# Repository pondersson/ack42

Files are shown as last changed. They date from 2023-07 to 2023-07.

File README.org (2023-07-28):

* ACK42

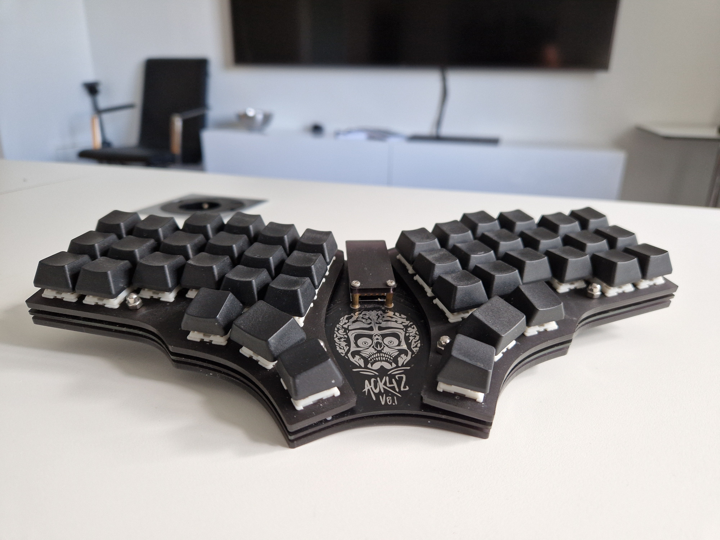
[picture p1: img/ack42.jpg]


ACK42 is a DIY sandwich-style keyboard with 42 keys inspired by [[https://zealot.hu/absolem/][Absolem]], [[https://github.com/foostan/crkbd][Corne]] and [[https://blog.splitkb.com/introducing-the-kyria/][Kyria]]. The first prototypes were assembled in September 2020 and they have miraculously survived daily use since then.

This repository is a dump of the artifacts left over from the creation process. Things might be broken, so take this not as a finished product ready to be sent off for manufacturing, but rather as a documented example of one way of creating a keyboard.

I briefly entertained the idea of skipping a PCB and instead 3D-printing wire channels and hand-wiring Kailh hotswap sockets (see [[#gallery][Gallery]]). In the end I went the PCB route and that was a good decision in hindsight. It made assembly much easier and I ended up making 4 versions of the keyboard: 2 MX hotswap versions and 2 Choc low-profile versions, 3 of which I still use regularly, some daily.

** Process (rough)

1) CAD top plate, spending countless hours shifting switch positions around a few millimeters at a time and 3D-printing prototypes until things feel just right
2) CAD everything else: bottom plate, screw holes, MCU cutout and cover
3) Dump top plate to a KiCad-friendly format so the outline and switch positions can be used during PCB design
4) Add all PCB components into KiCad, connect them in the electric schematic and then on the PCB
5) Import top plate into KiCad and painstakingly rotate and position all switch footprints so they're lined up with the top plate
6) Add some art to give the PCB some flair
7) Export Gerber files from KiCad and send them off to the manufacturer
8) Export all necessary SVG files from OpenSCAD, tile them neatly in a single SVG file that represent an acrylic sheet and send it off for laser cutting
9) Order all other necessary components (see [[#materials][Materials]])
10) Wait for parts to arrive
11) Assemble the keyboard(s)
   
**  Materials

All parts required to assemble a single ACK42 keyboard (MX variant):

- 1 ACK42 PCB
- 1 Elite-C microcontroller with pins + stand-offs
- 8 M3 12 mm screws
- 8 M3 cap nuts
- 2 M2 screws
- 2 M2 stand-offs
- 64 0.5 mm washers (or equivalent)
- 42 Kailh hotswap sockets
- 42 through-hole diodes
- 42 MX-style switches
- 42 Keycaps
   
** Gallery

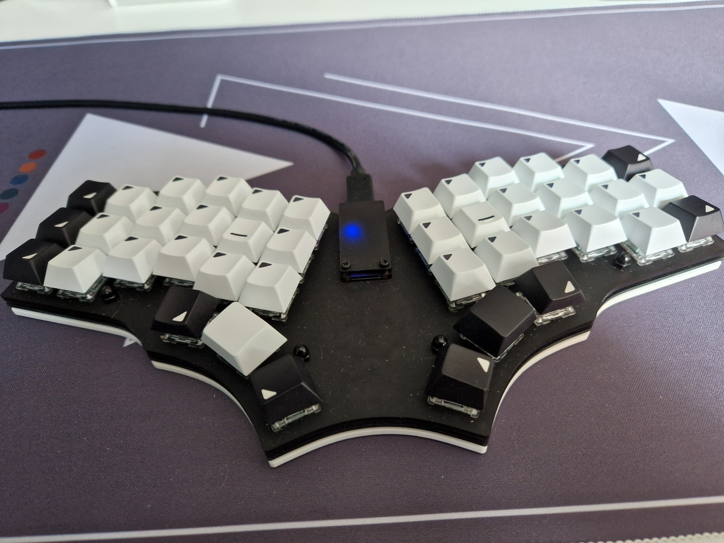
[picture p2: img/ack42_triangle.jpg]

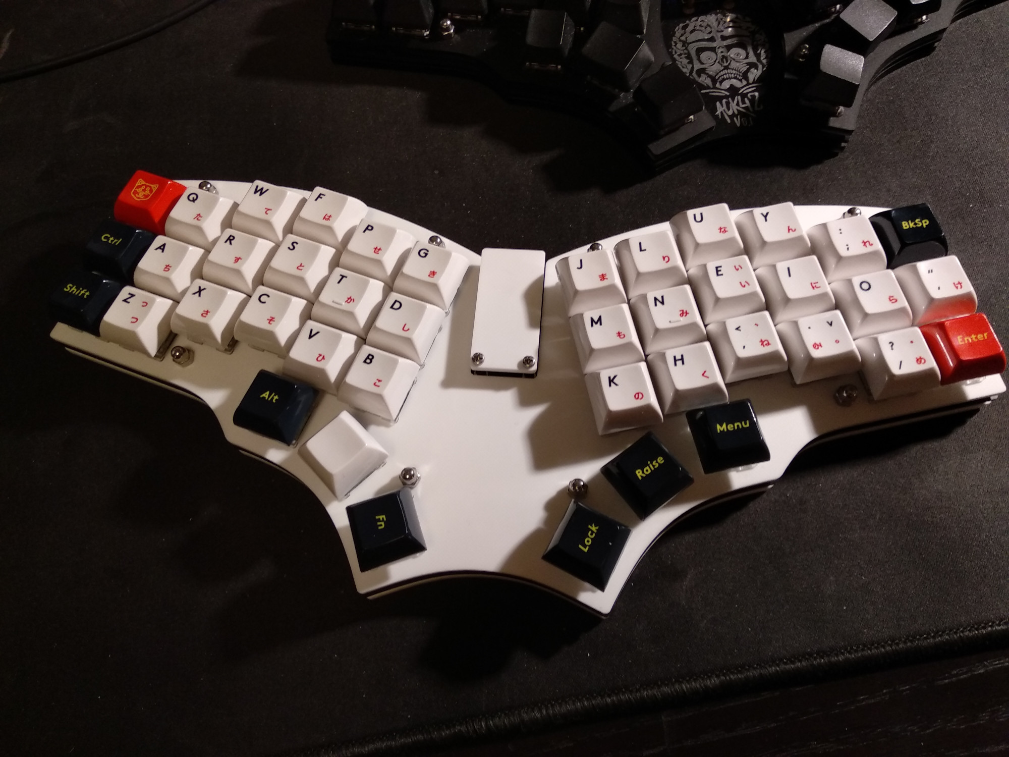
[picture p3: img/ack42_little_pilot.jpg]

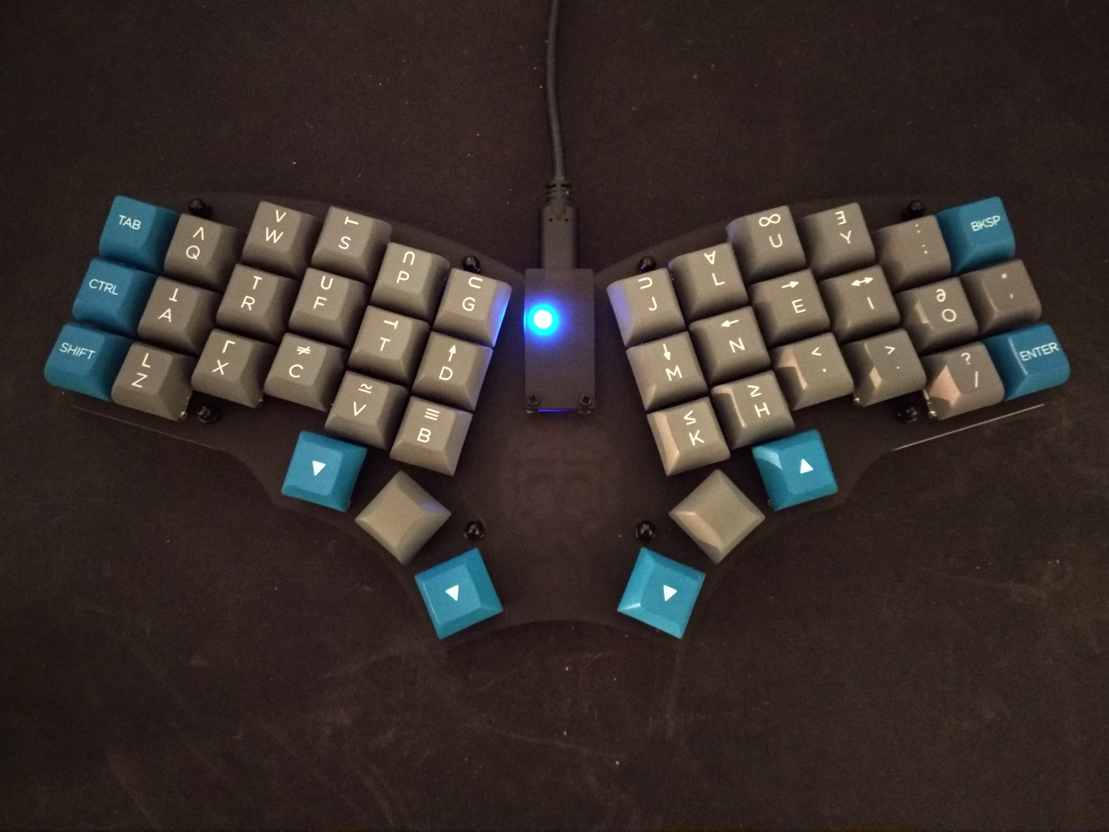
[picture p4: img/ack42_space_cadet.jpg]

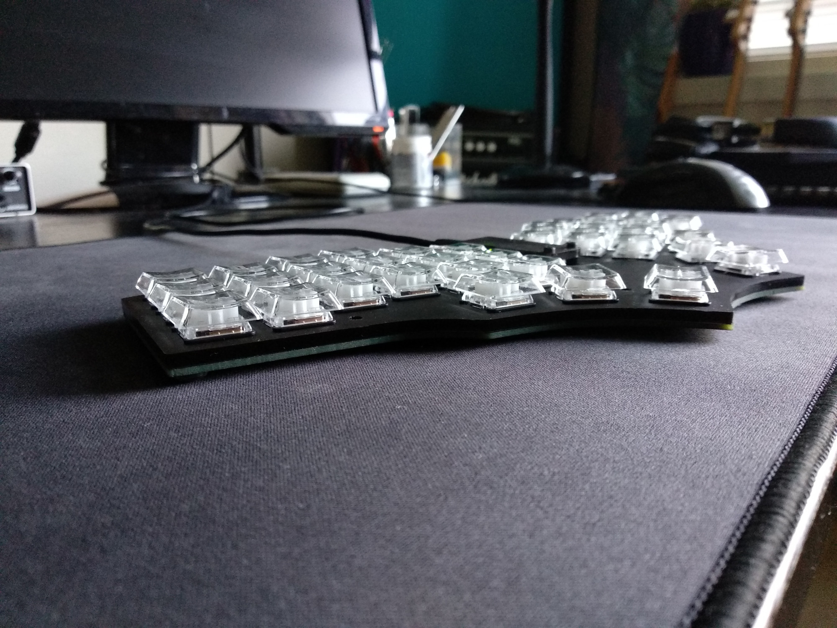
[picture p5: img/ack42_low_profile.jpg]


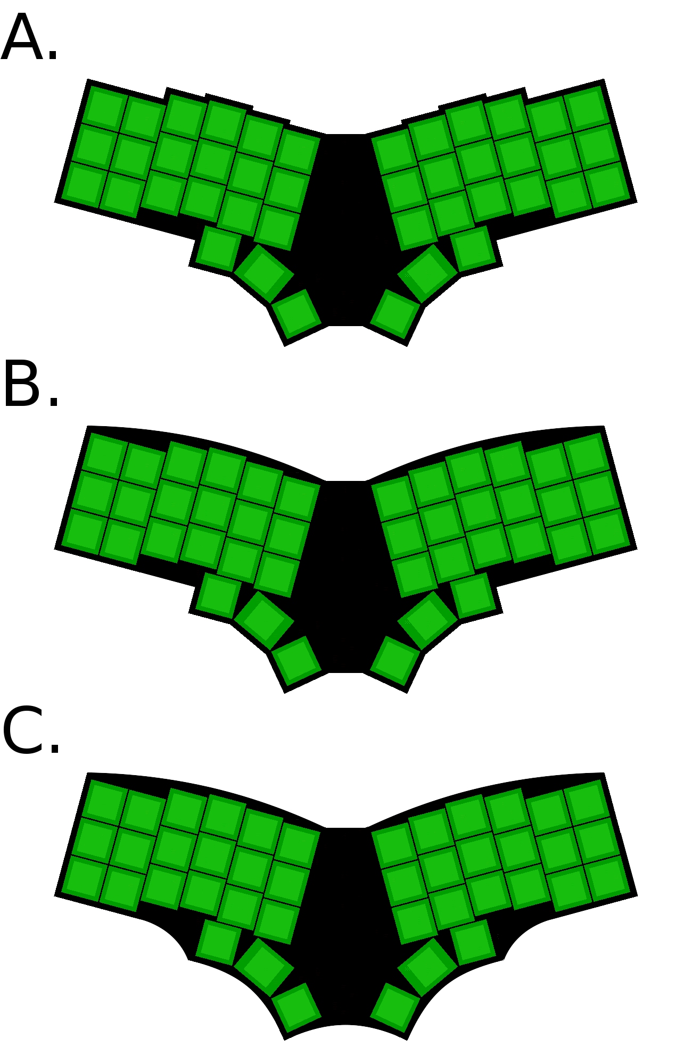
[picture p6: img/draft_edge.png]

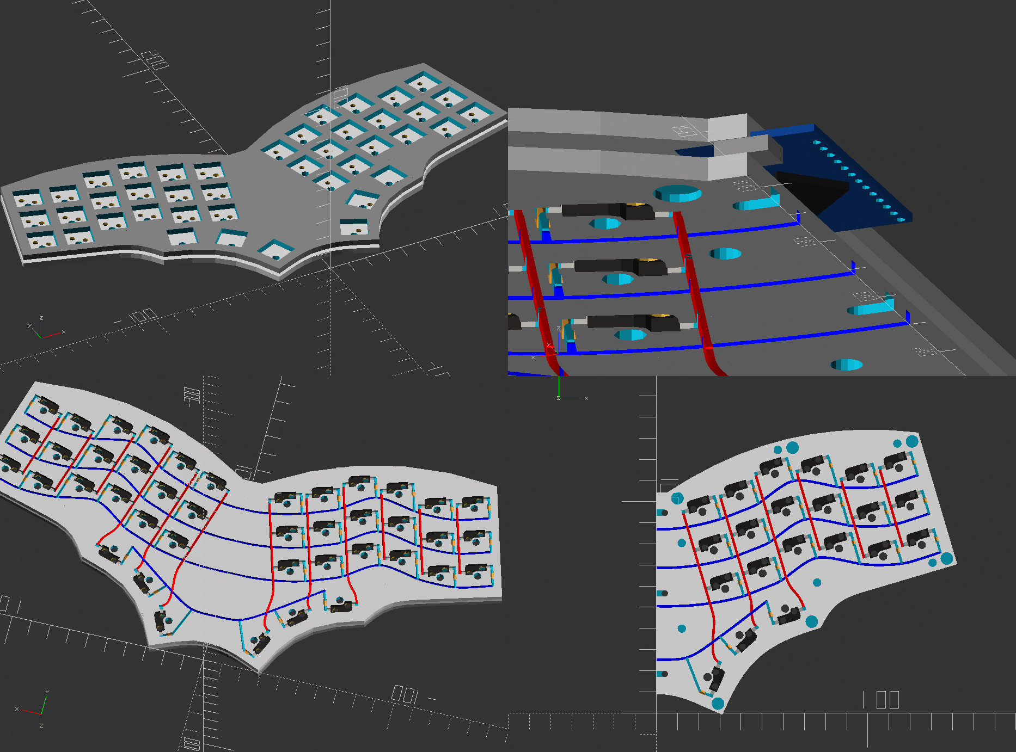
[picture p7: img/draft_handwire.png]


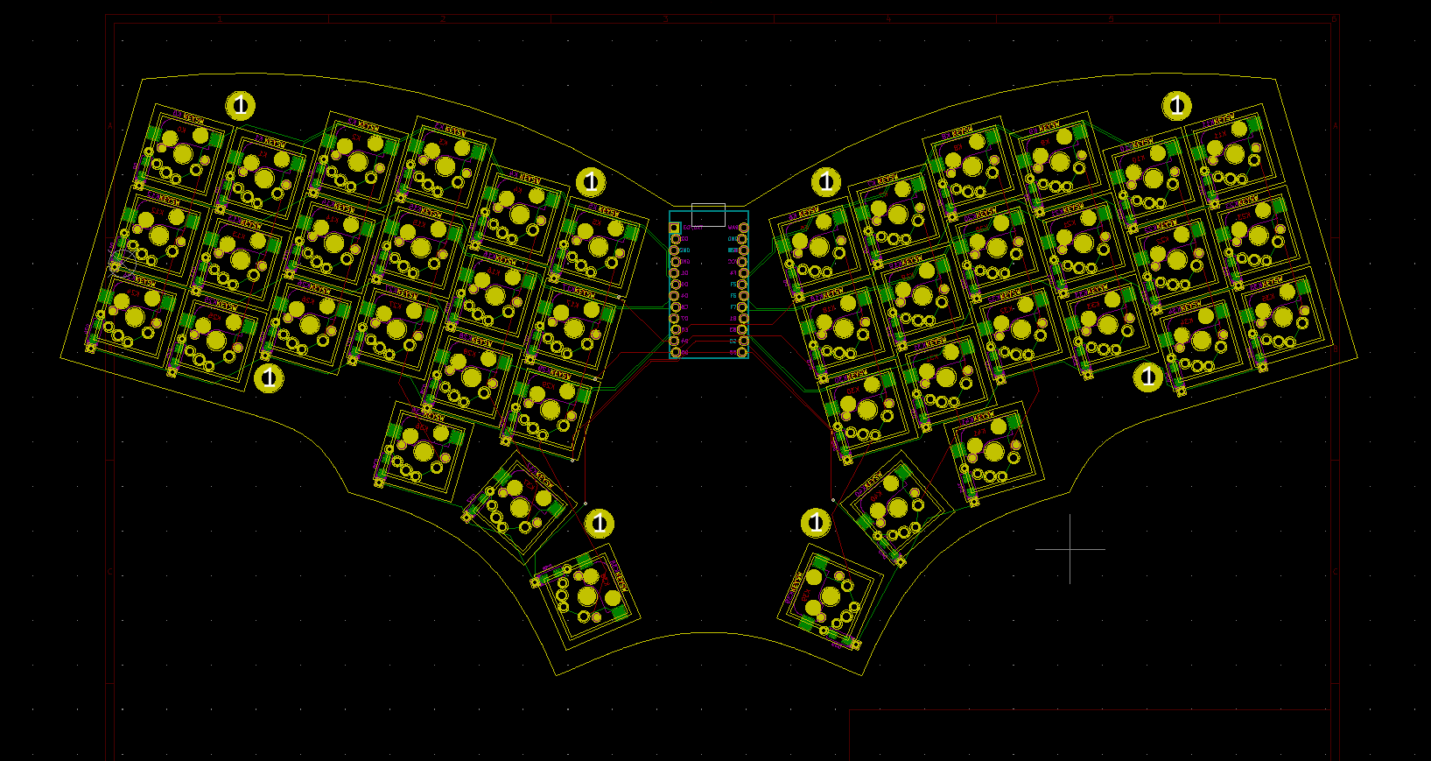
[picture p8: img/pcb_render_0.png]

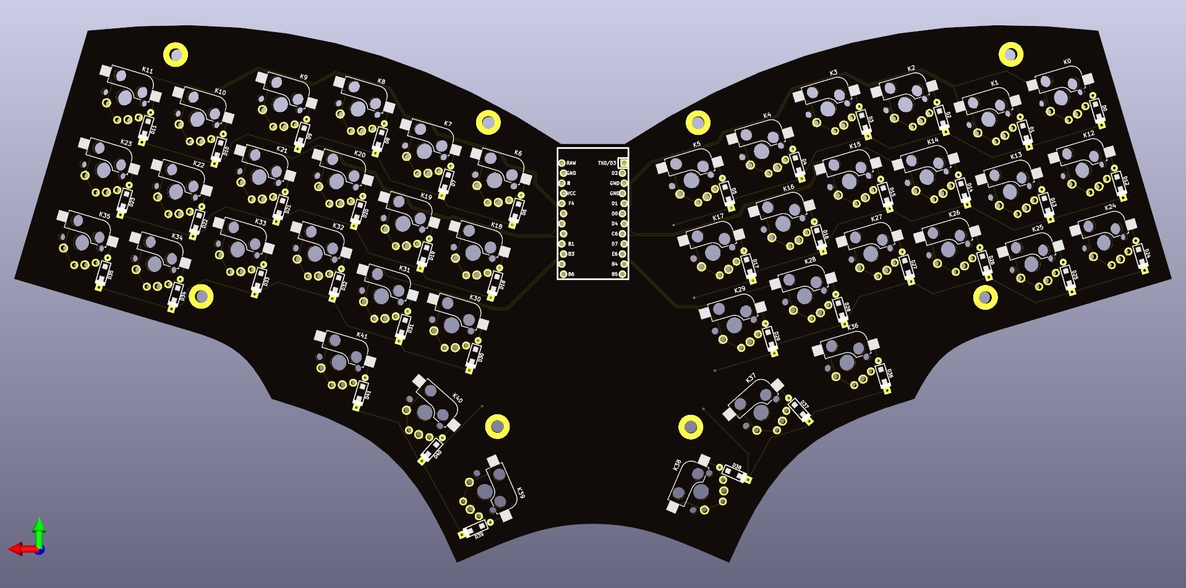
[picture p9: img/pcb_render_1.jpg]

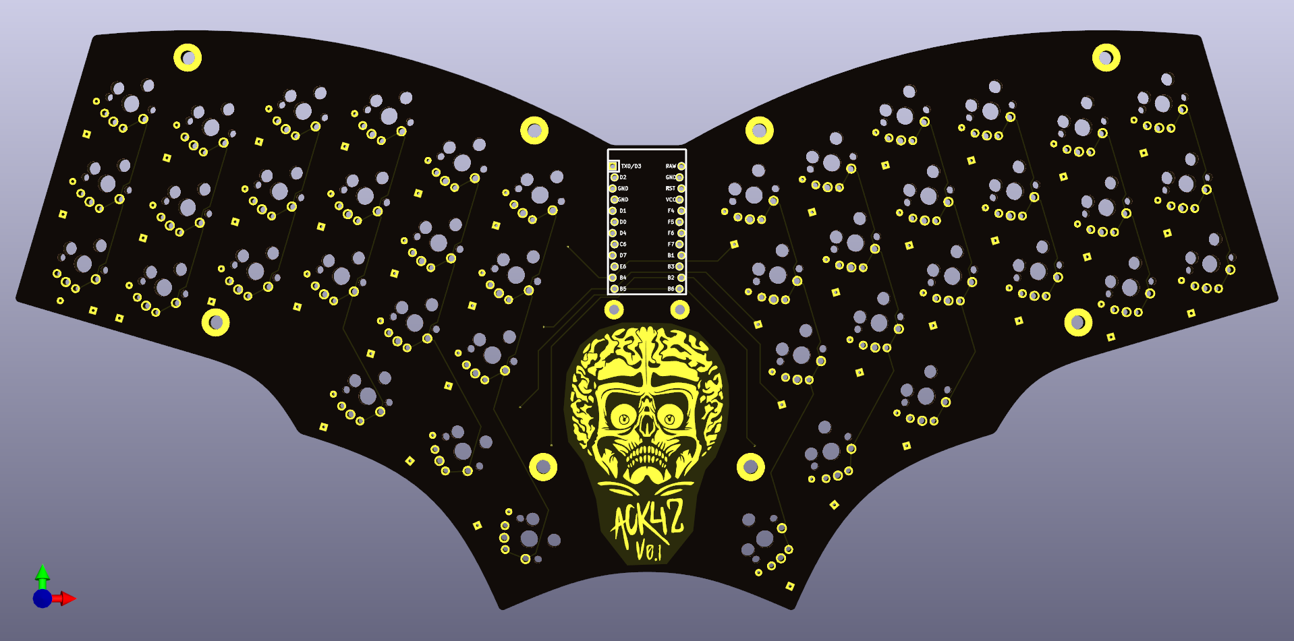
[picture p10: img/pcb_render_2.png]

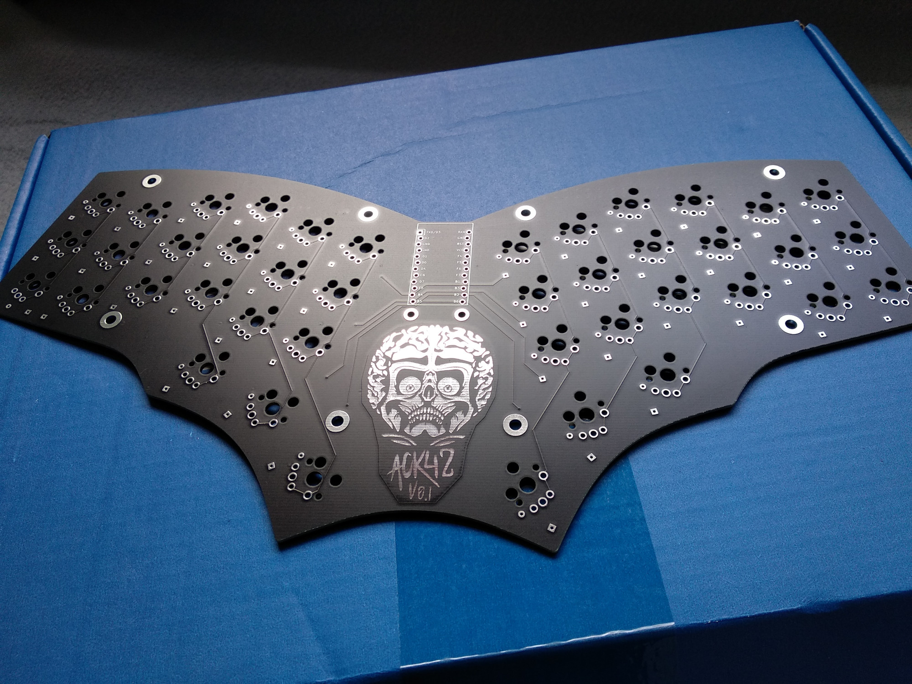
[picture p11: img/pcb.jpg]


** License
[[file:LICENSE]] © Pontus Andersson

The KiCad components were taken from the following repositories and their licenses can be found in the corresponding ~pcb~ subdirectories:

- https://github.com/daprice/keyswitches.pretty
- https://github.com/keebio/Keebio-Parts.pretty
- https://github.com/tmk/keyboard_parts.pretty

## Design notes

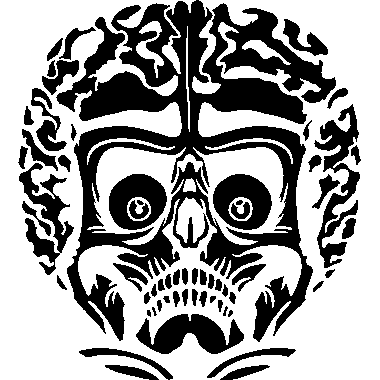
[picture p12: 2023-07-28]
pcb/art/alien.png

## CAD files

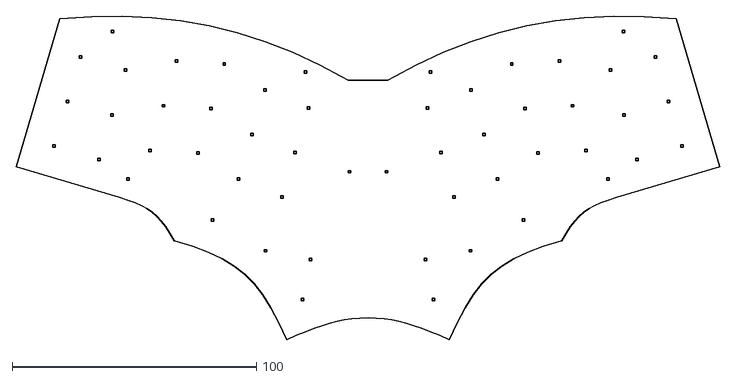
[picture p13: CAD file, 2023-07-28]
pcb/outline.dxf
288.0 x 132.4

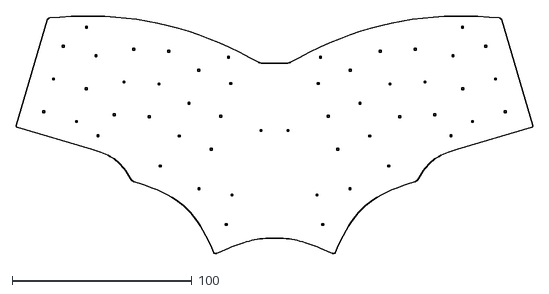
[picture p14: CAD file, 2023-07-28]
pcb/pcb.dxf
287.5 x 132.2

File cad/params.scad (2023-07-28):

// Global parameters
$fn = 16;         // number of facets used when drawing arcs
cut_delta = 0.01; // small nudge to help with rendering
kerf = 0.0;       // laser cutting kerf

u = 19.05;        // measured 18.75 (?) on helidox, cherry spec is 19.05
su_t = 3.0;       // switch unit (plate) thickness
sh = 14.0 - kerf; // switch hole side length

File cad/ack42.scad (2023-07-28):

// ** IMPORTS **
include <params.scad>
use <util/bezier_curve.scad>
use <util/util.scad>
use <util/spline.scad>

// ** TOGGLES **
draw_caps = false;
// Extras: {0-2: fill slabs, 3: mcu cover, 4: mcu cutout}
draw_extra = [true, true, true, false, true];
// Bezier elements going around the edge
draw_bezier = [true, true, true, true];

// ** PARAMETERS **
// Top plate
pad = 3.0;            // switch unit pad (outline border width)
su = u + 2*pad;       // switch unit side length (the chunks that make up the top plate)
p_mw = 16.0;          // plate mid-width
split_angle = 16.5;   // angle between halves, 16.5
bezier_t_step = 0.05; // smoothness of Bezier curves

// ** MATRIX SETUP **
// These are now fixed parameters
n_cols = 6;
n_rows = 3;
col_stagger = [-2, 0, 5.5, 1, -8.5, -8.5];

// Generate coordinates for matrix key positions
// Matrix index [0, 0] corresponds to the bottom inner key
m_offset = [20, 45];
m_x = [ for (r = [ 0 : n_rows - 1 ]) [ for (c = [ 0 : n_cols - 1 ])
    m_offset[0] + c*u ] ];
m_y = [ for (r = [ 0 : n_rows - 1 ]) [ for (c = [ 0 : n_cols - 1 ])
    m_offset[1] + r*u + col_stagger[c] ] ];

// ** THUMB CLUSTER **
// Generate coordinates for the thumb key positions
// Thumb key index runs inward, i.e. 0 is the straight one
t_w = 1.25; // keycap size in units of the middle thumb key
t_a = 25; tc_x = -4; tc_y = 0; // thumb cluster angle, x- and y-offset
t0_x = 0.5*(m_x[0][1] + m_x[0][2]) + tc_x;
t0_y = m_y[0][1] - u + tc_y;
t1_x = t0_x - t_w*u*cos(t_a);
t1_y = t0_y - t_w*u*sin(t_a);
t2_x = t1_x - u*cos(2*t_a);
t2_y = t1_y - u*sin(2*t_a);
t_x = [t0_x, t1_x, t2_x];
t_y = [t0_y, t1_y, t2_y];

// Thumb slabs, how far to extend the thumb switch units left/right/down/up
ts = [[5, 0, 0, 0],
      [1, 2, 0, 0],
      [0, 40, 0, 0]];
tw = [1, t_w, 1];

// ** EXTRA SLABS **
// Extra slabs to fill certain gaps
es_0 = [0, 0, 10, 0]; // left, right, down, up
es_1 = [0, 0, col_stagger[2] - col_stagger[3], 0]; // left, right, down, up
es_20 = [m_x[2][0] - pad, m_y[2][0] + u + pad + 3];
es_2_vec = rot2([-1, 0], -split_angle);
es_21 = es_20 + p_mw/2*es_2_vec;
es_23 = [t2_x, t2_y] + rot2([-pad, u + pad], 2*t_a);
es_2_proj = (es_23 - es_21)*es_2_vec; // vector dot product
es_22 = (es_2_proj < 0) ? es_23 - es_2_proj*es_2_vec : es_23;
es_24 = [m_x[0][0], m_y[0][0]];
es_2_pts = (es_2_proj < 0) ? [es_20, es_21, es_22, es_23, es_24, es_20] : [es_20, es_21, es_23, es_24, es_20];

// Microcontroller cutout
mcu_pad = 1;
mcu_width = 18 + 2*mcu_pad;
mcu_length = 33 + 2*mcu_pad;

// Microcontroller cover
mcov_rscrew = 2.5;
mcov_rscrew_hole = 1.1;
mcov_offset = mcu_length + 2*mcov_rscrew;
mcov_length = mcov_offset + 1.0;
mcov_width = mcu_width;
mcov_height = su_t + 2;
mcov_thickness = 3;
mcov_screw_xoffset = mcov_width/2 - mcov_rscrew;

// Translation vector to align with the y-axis for mirroring
shift_vec = rot2(es_22, split_angle);

// ** KEYCAPS **
c_col = [0.0, 0.0, 0.0, 0.8]; // color
c_w = 18.3;                   // width
c_h = 5;                      // height
c_z = 7.00;                   // height above plate

// ** BEZIER EDGES **
// Defined in XY-plane and then extruded into Z
module symmetric_bezier_element(p1, p2, weight, angle, extra_points=[], height=1) {
  diff = p2 - p1;
  b1 = p1 + weight*rot2(diff, angle);
  b2 = p2 - weight*rot2(diff, -angle);
  pts = [p1, b1, b2, p2];
  curve = bezier_curve(bezier_t_step, pts);
  poly = concat(curve, extra_points, [p1]);
  linear_extrude(height) {polygon(points=poly);}
}

// Bezier 0
b0_w = 0.365;
b0_a = 17.5;
b0_p1 = es_20;
b0_p2 = [m_x[2][5] + u + pad, m_y[2][5] + u + pad];
b0_p3 = [m_x[2][5] + u + pad, m_y[2][5] - pad];
b0_p4 = [m_x[2][0] - pad, m_y[2][0] - pad];
b0_extra = [b0_p3, b0_p4];

// Bezier 1
b1_w = 0.45;
b1_p1 = [m_x[0][4] - pad, m_y[0][4] - pad];
b1_p2 = [t0_x + u + pad, t0_y - pad];
b1_diff = b1_p2 - b1_p1;
b1_a = -atan(abs(b1_diff[1]/b1_diff[0]));
b1_p3 = [t0_x + u + pad, t0_y + u + pad];
b1_p4 = [m_x[0][3] + u + pad, m_y[0][3] - pad];
b1_extra = [b1_p3, b1_p4];

// Bezier 2
b2_w = 0.45;
b2_p1 = [t0_x + u + pad, t0_y - pad];
b2_p2 = [t2_x, t2_y] + rot2([-pad, -pad], 2*t_a);
b2_diff = b2_p2 - b2_p1;
b2_a = -atan(abs(b2_diff[1]/b2_diff[0]));
b2_p3 = [t1_x, t1_y] + rot2([t_w*u, u], 2*t_a);
b2_extra = [b2_p3];

// Bezier 3, asymmetric to get horizontal tangent at the bottom where the two halves meet
b3_w1 = 0.45;
b3_w2 = 0.35;
b3_drop = 1;
b3_p1 = [t2_x, t2_y] + rot2([-pad, -pad], 2*t_a);
b3_p2 = es_22 + rot2([0, -b3_drop], -split_angle);
b3_diff = b3_p2 - b3_p1;
b3_a1 = -((90 - 2*t_a) - atan(abs(b3_diff[1]/b3_diff[0])));
b3_b1 = b3_p1 + b3_w1*rot2(b3_diff, b3_a1);
// b3_p2 is the special point, its tangent vector should be [1, 0]
b3_vec2 = rot2([1, 0], -split_angle);
b3_vec2_full = (b3_diff*b3_vec2)*b3_vec2;
b3_b2 = b3_p2 - b3_w2*b3_vec2_full;
b3_pts = [b3_p1, b3_b1, b3_b2, b3_p2];
b3_curve = bezier_curve(bezier_t_step, b3_pts);
b3_p3 = es_22;
b3_p4 = [t2_x, t2_y] + rot2([u, u], 2*t_a);
b3_poly = concat(b3_curve, [b3_p3, b3_p4, b3_p1]);

// ** MOUNTING HOLES **
mh_min_radius = (3.0 + 0.2)/2; // assuming M3
mh_max_radius = 6.4/2;
mh1 = [m_x[2][1] - mh_max_radius - 1, m_y[2][0] + u + mh_max_radius + 1];
mh2 = [m_x[2][5], m_y[2][5] + u + mh_max_radius + 1];
mh3 = [t1_x, t1_y] + rot2([-0.22*u, u], t_a);
mh4 = [m_x[0][4] - mh_max_radius - 1, m_y[0][3] - mh_max_radius - 1];
mh_points = [mh1, mh2, mh3, mh4];

// ** BUILD **
// The only difference between top and bottom plates are the cutouts
module ack42(top, col) {
  difference() {
    union() {
      color (col) {
        // Render matrix switch units
        for(r = [0 : n_rows - 1]) {
          for(c = [0 : n_cols - 1]) {
            translate([m_x[r][c] - pad, m_y[r][c] - pad, 0])
              if(r==2 && c==2) {
                cube([su, su - pad, su_t]);
              }
              else {
                cube([su, su, su_t]);
              }
          }
        }
        // Render thumb switch units
        for(i = [0 : 2]) {
          translate([t_x[i], t_y[i], 0])
            rotate([0, 0, i*t_a])
            translate([-ts[i][0] - pad, -ts[i][2] - pad, 0])
            cube([tw[i]*su + ts[i][0] + ts[i][1], su + ts[i][2] + ts[i][3], su_t]);
        }
        // Render extra slabs
        if(draw_extra[0]) {
          translate([m_x[0][0], m_y[0][0], 0])
            translate([-es_0[0], -es_0[2], 0])
            cube([su + es_0[0] + es_0[1], su + es_0[2] + es_0[3], su_t]);
        }
        if(draw_extra[1]) {
          translate([m_x[0][2], m_y[0][2], 0])
            translate([-es_1[0], -es_1[2], 0])
            cube([su + es_1[0] + es_1[1], su + es_1[2] + es_1[3], su_t]);
        }
        if(draw_extra[2]) {
          linear_extrude(height=su_t) {polygon(points=es_2_pts);}
        }
        // Render Bezier elements
        if(draw_bezier[0])
          symmetric_bezier_element(b0_p1, b0_p2, b0_w, b0_a, b0_extra, su_t);
        if(draw_bezier[1])
          symmetric_bezier_element(b1_p1, b1_p2, b1_w, b1_a, b1_extra, su_t);
        if(draw_bezier[2])
          symmetric_bezier_element(b2_p1, b2_p2, b2_w, b2_a, b2_extra, su_t);
        if(draw_bezier[3])
          linear_extrude(height=su_t) {polygon(points=b3_poly);}

      }
      // Render microcontroller cover
      if (top && draw_extra[3]) {
        translate(es_21)
          rotate([0, 0, -split_angle])
          translate([0, -mcov_offset, mcov_height])
          difference() {
          color([0.2, 0.2, 0.2, 0.80])
            cube([mcov_width/2, mcov_length, mcov_thickness]);
          translate([mcov_screw_xoffset, mcov_rscrew, mcov_thickness/2])
            cylinder(h=mcov_thickness + 2*cut_delta, r=mcov_rscrew_hole, center=true);
        }
      }
    }

    // Top plate cutouts
    if (top) {
      // Cut out matrix switch holes
      for(r = [0 : n_rows - 1]) {
        for(c = [0 : n_cols - 1]) {
          translate([m_x[r][c] + (u - sh)/2, m_y[r][c] + (u - sh)/2, -cut_delta]) {
            cube([sh, sh, su_t + 2*cut_delta]);
          }
        }
      }
      // Cut out thumb switch holes
      for(i = [0 : 2]) {
        translate([t_x[i], t_y[i], -cut_delta])
          rotate([0, 0, i*t_a])
          translate([(tw[i]*u - sh)/2, (u - sh)/2, 0]) {
          cube([sh, sh, su_t + 2*cut_delta]);
        }
      }
      // Microcontroller cutout
      if (top && draw_extra[4]) {
        translate(es_21)
          rotate([0, 0, -split_angle])
          translate([-cut_delta, -mcov_offset + kerf/2, -cut_delta])
          cube([mcu_width/2 - kerf/2 + cut_delta, mcu_length - kerf/2 + 10, su_t + 2*cut_delta]); // add 10 to height to cut through the Bezier element
      }
    }
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

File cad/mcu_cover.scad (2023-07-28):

include <params.scad>

length = 41.0;
width = 20.0;
thickness = 3.0;
rscrew = 2.5;
rscrew_hole = 1.1;
screw_xoffset = width/2 - rscrew;

module mcu_cover() {
  difference() {
    cube([width + kerf, length + kerf, thickness]);
    translate([kerf/2, kerf/2, 0]) {
      translate([width/2 - screw_xoffset, rscrew, thickness/2])
        cylinder(h=thickness + 2*cut_delta, r=rscrew_hole, center=true);
      translate([width/2 + screw_xoffset, rscrew, thickness/2])
        cylinder(h=thickness + 2*cut_delta, r=rscrew_hole, center=true);
    }
  }
}

projection() {
  mcu_cover();
}

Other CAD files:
cad/util/bezier_curve.scad
cad/util/spline.scad
cad/util/util.scad

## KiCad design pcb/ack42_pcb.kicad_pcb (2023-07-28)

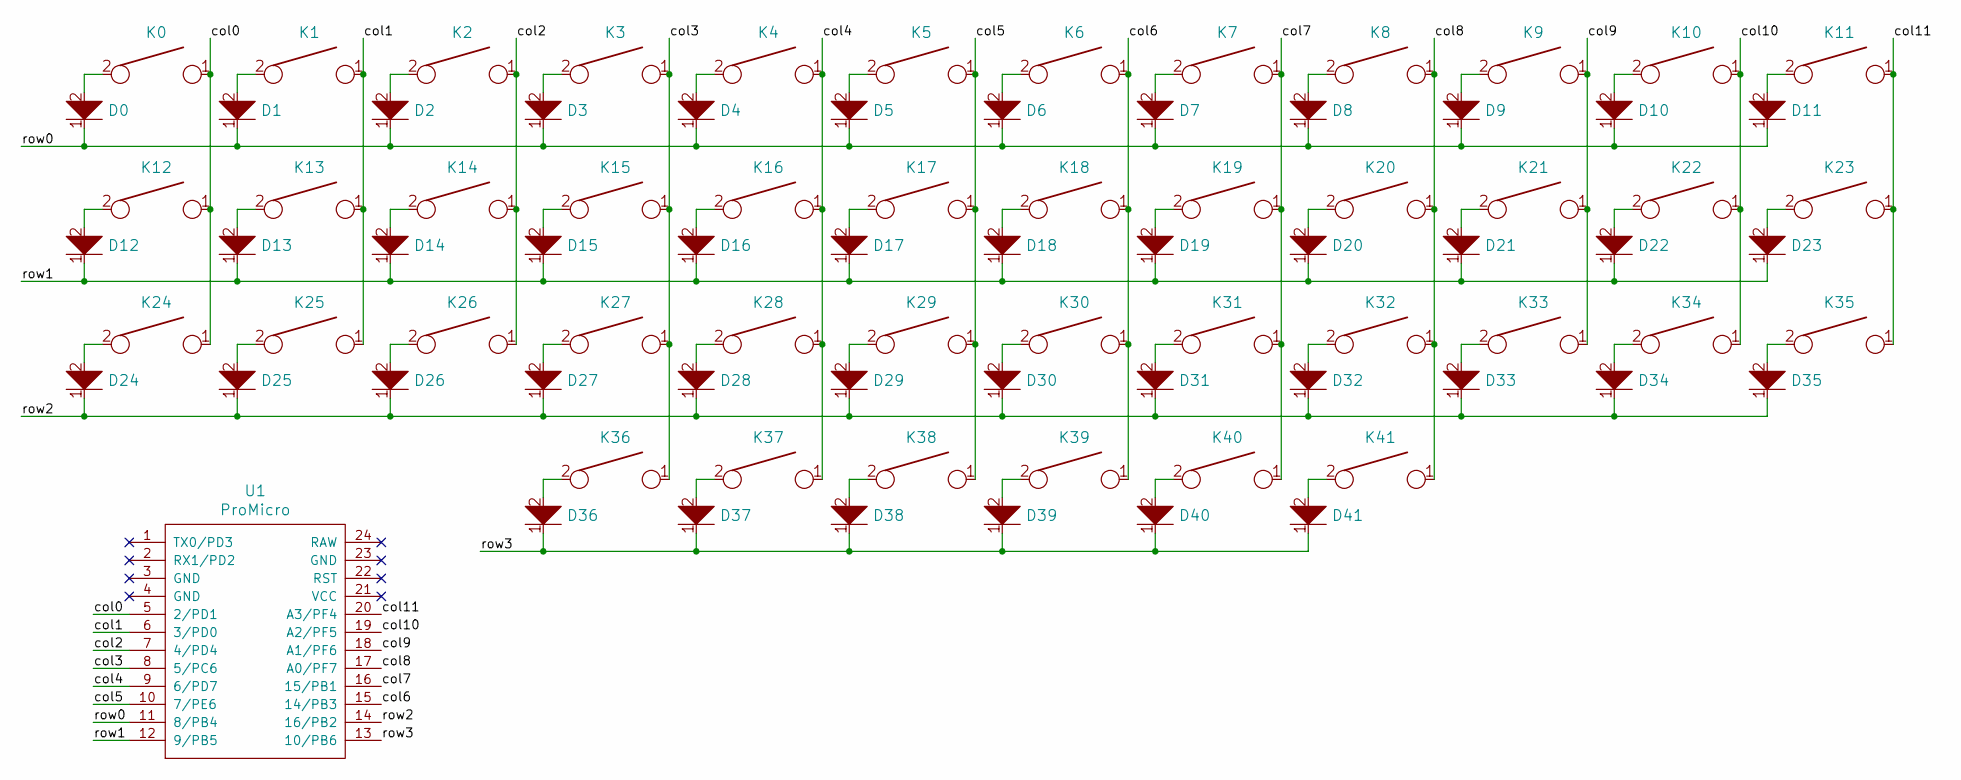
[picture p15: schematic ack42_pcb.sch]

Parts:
D0, D1, D2, D3, D4, D5, D6, D7, D8, D9, D10, D11, D12, D13, D14, D15, D16, D17, D18, D19, D20, D21, D22, D23, D24, D25, D26, D27, D28, D29, D30, D31, D32, D33, D34, D35, D36, D37, D38, D39, D40, D41: D; D_SOD123_axial
K0, K1, K2, K3, K4, K5, K6, K7, K8, K9, K10, K11, K12, K13, K14, K15, K16, K17, K18, K19, K20, K21, K22, K23, K24, K25, K26, K27, K28, K29, K30, K31, K32, K33, K34, K35, K36, K37, K38, K39, K40, K41: KEYSW; Kailh_socket_MX1350_optional
U1: ProMicro; ArduinoProMicro-ZigZag

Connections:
/col0: K0.1, K12.1, K24.1, U1.5 (2/PD1)
/col1: K1.1, K13.1, K25.1, U1.6 (3/PD0)
/col2: K2.1, K14.1, K26.1, U1.7 (4/PD4)
/col3: K3.1, K15.1, K27.1, K36.1, U1.8 (5/PC6)
/col4: K4.1, K16.1, K28.1, K37.1, U1.9 (6/PD7)
/col5: K5.1, K17.1, K29.1, K38.1, U1.10 (7/PE6)
/col6: K6.1, K18.1, K30.1, K39.1, U1.15 (14/PB3)
/col7: K7.1, K19.1, K31.1, K40.1, U1.16 (15/PB1)
/col8: K8.1, K20.1, K32.1, K41.1, U1.17 (A0/PF7)
/col9: K9.1, K21.1, K33.1, U1.18 (A1/PF6)
/col10: K10.1, K22.1, K34.1, U1.19 (A2/PF5)
/col11: K11.1, K23.1, K35.1, U1.20 (A3/PF4)
/row0: D0.1, D1.1, D2.1, D3.1, D4.1, D5.1, D6.1, D7.1, D8.1, D9.1, D10.1, D11.1, U1.11 (8/PB4)
/row1: D12.1, D13.1, D14.1, D15.1, D16.1, D17.1, D18.1, D19.1, D20.1, D21.1, D22.1, D23.1, U1.12 (9/PB5)
/row2: D24.1, D25.1, D26.1, D27.1, D28.1, D29.1, D30.1, D31.1, D32.1, D33.1, D34.1, D35.1, U1.14 (16/PB2)
/row3: D36.1, D37.1, D38.1, D39.1, D40.1, D41.1, U1.13 (10/PB6)
unnamed: D0.2, K0.2
unnamed: D1.2, K1.2
unnamed: D2.2, K2.2
unnamed: D3.2, K3.2
unnamed: D4.2, K4.2
unnamed: D5.2, K5.2
unnamed: D6.2, K6.2
unnamed: D7.2, K7.2
unnamed: D8.2, K8.2
unnamed: D9.2, K9.2
unnamed: D10.2, K10.2
unnamed: D11.2, K11.2
unnamed: D12.2, K12.2
unnamed: D13.2, K13.2
unnamed: D14.2, K14.2
unnamed: D15.2, K15.2
unnamed: D16.2, K16.2
unnamed: D17.2, K17.2
unnamed: D18.2, K18.2
unnamed: D19.2, K19.2
unnamed: D20.2, K20.2
unnamed: D21.2, K21.2
unnamed: D22.2, K22.2
unnamed: D23.2, K23.2
unnamed: D24.2, K24.2
unnamed: D25.2, K25.2
unnamed: D26.2, K26.2
unnamed: D27.2, K27.2
unnamed: D28.2, K28.2
unnamed: D29.2, K29.2
unnamed: D30.2, K30.2
unnamed: D31.2, K31.2
unnamed: D32.2, K32.2
unnamed: D33.2, K33.2
unnamed: D34.2, K34.2
unnamed: D35.2, K35.2
unnamed: D36.2, K36.2
unnamed: D37.2, K37.2
unnamed: D38.2, K38.2
unnamed: D39.2, K39.2
unnamed: D40.2, K40.2
unnamed: D41.2, K41.2

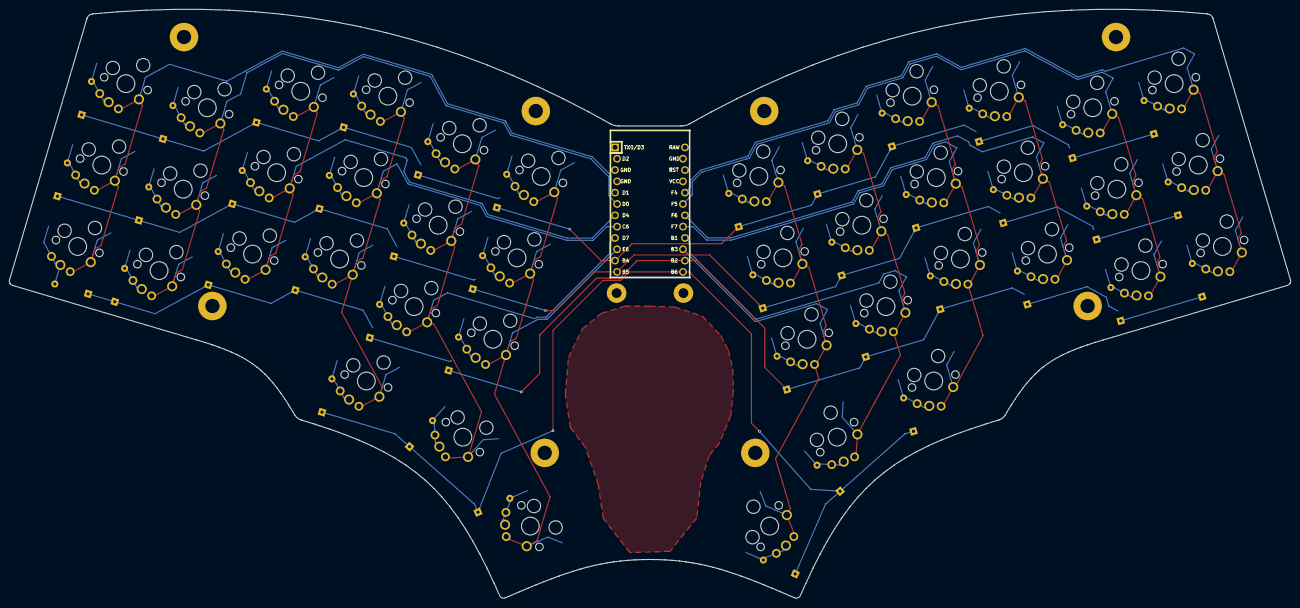
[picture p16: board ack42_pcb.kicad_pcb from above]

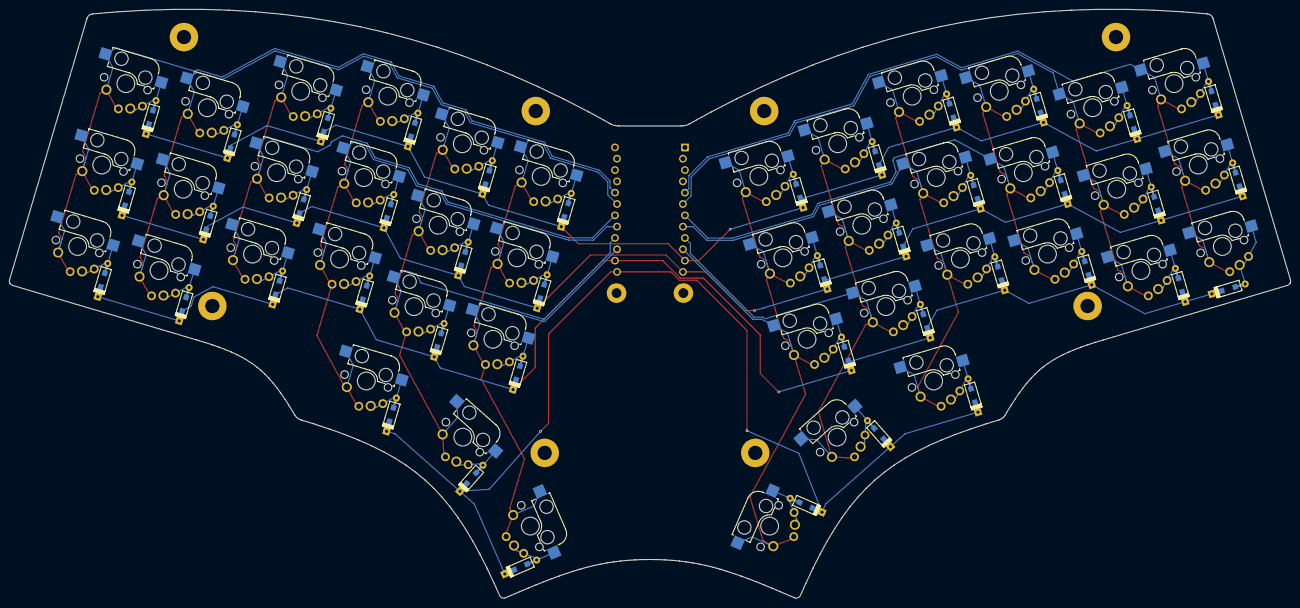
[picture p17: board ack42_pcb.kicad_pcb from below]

Board: 2 copper layers, 287.5 x 132.1 mm, 96 parts (42 on the bottom side), 58 nets.

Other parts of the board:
HOLE_M3, HOLE_M3#2: VAL**; HOLE_M2
HOLE_M3#3, HOLE_M3#4, HOLE_M3#5, HOLE_M3#6, HOLE_M3#7, HOLE_M3#8, HOLE_M3#9, HOLE_M3#10: VAL**; HOLE_M3
svg2mod: G***; ack42

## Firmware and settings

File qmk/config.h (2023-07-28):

/*
Copyright 2020 pondersson

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
You should have received a copy of the GNU General Public License
along with this program.  If not, see <http://www.gnu.org/licenses/>.
*/

#pragma once

#include "config_common.h"

/* USB Device descriptor parameter */
#define VENDOR_ID    0xF055
#define PRODUCT_ID   0x000a
#define DEVICE_VER   0x0001
#define MANUFACTURER pondersson
#define PRODUCT      ACK42
#define DESCRIPTION  Ergonomic keyboard

/* key matrix size */
#define MATRIX_ROWS 4
#define MATRIX_COLS 12

/*
 * Keyboard Matrix Assignments
 *
 * Change this to how you wired your keyboard
 * COLS: AVR pins used for columns, left to right
 * ROWS: AVR pins used for rows, top to bottom
 * DIODE_DIRECTION: COL2ROW = COL = Anode (+), ROW = Cathode (-, marked on diode)
 *                  ROW2COL = ROW = Anode (+), COL = Cathode (-, marked on diode)
 *
 */
#define MATRIX_ROW_PINS { B4, B5, B2, B6 }
#define MATRIX_COL_PINS { D1, D0, D4, C6, D7, E6, B3, B1, F7, F6, F5, F4 }
#define UNUSED_PINS

/* COL2ROW, ROW2COL */
#define DIODE_DIRECTION COL2ROW

/*
 * Split Keyboard specific options, make sure you have 'SPLIT_KEYBOARD = yes' in your rules.mk, and define SOFT_SERIAL_PIN.
 */
#define SOFT_SERIAL_PIN D0  // or D1, D2, D3, E6

//#define BACKLIGHT_PIN B7
//#define BACKLIGHT_LEVELS 3
//#define BACKLIGHT_BREATHING

//#define RGB_DI_PIN E2
//#ifdef RGB_DI_PIN
//#    define RGBLED_NUM 16
//#    define RGBLIGHT_HUE_STEP 8
//#    define RGBLIGHT_SAT_STEP 8
//#    define RGBLIGHT_VAL_STEP 8
//#    define RGBLIGHT_LIMIT_VAL 255 /* The maximum brightness level */
//#    define RGBLIGHT_SLEEP  /* If defined, the RGB lighting will be switched off when the host goes to sleep */
/*== all animations enable ==*/
//#    define RGBLIGHT_ANIMATIONS
/*== or choose animations ==*/
//#    define RGBLIGHT_EFFECT_BREATHING
//#    define RGBLIGHT_EFFECT_RAINBOW_MOOD
//#    define RGBLIGHT_EFFECT_RAINBOW_SWIRL
//#    define RGBLIGHT_EFFECT_SNAKE
//#    define RGBLIGHT_EFFECT_KNIGHT
//#    define RGBLIGHT_EFFECT_CHRISTMAS
//#    define RGBLIGHT_EFFECT_STATIC_GRADIENT
//#    define RGBLIGHT_EFFECT_RGB_TEST
//#    define RGBLIGHT_EFFECT_ALTERNATING
/*== customize breathing effect ==*/
/*==== (DEFAULT) use fixed table instead of exp() and sin() ====*/
//#    define RGBLIGHT_BREATHE_TABLE_SIZE 256      // 256(default) or 128 or 64
/*==== use exp() and sin() ====*/
//#    define RGBLIGHT_EFFECT_BREATHE_CENTER 1.85  // 1 to 2.7
//#    define RGBLIGHT_EFFECT_BREATHE_MAX    255   // 0 to 255
//#endif

/* Debounce reduces chatter (unintended double-presses) - set 0 if debouncing is not needed */
#define DEBOUNCE 5

/* define if matrix has ghost (lacks anti-ghosting diodes) */
//#define MATRIX_HAS_GHOST

/* Mechanical locking support. Use KC_LCAP, KC_LNUM or KC_LSCR instead in keymap */
#define LOCKING_SUPPORT_ENABLE
/* Locking resynchronize hack */
#define LOCKING_RESYNC_ENABLE

/* If defined, GRAVE_ESC will always act as ESC when CTRL is held.
 * This is useful for the Windows task manager shortcut (ctrl+shift+esc).
 */
//#define GRAVE_ESC_CTRL_OVERRIDE

/*
 * Force NKRO
 *
 * Force NKRO (nKey Rollover) to be enabled by default, regardless of the saved
 * state in the bootmagic EEPROM settings. (Note that NKRO must be enabled in the
 * makefile for this to work.)
 *
 * If forced on, NKRO can be disabled via magic key (default = LShift+RShift+N)
 * until the next keyboard reset.
 *
 * NKRO may prevent your keystrokes from being detected in the BIOS, but it is
 * fully operational during normal computer usage.
 *
 * For a less heavy-handed approach, enable NKRO via magic key (LShift+RShift+N)
 * or via bootmagic (hold SPACE+N while plugging in the keyboard). Once set by
 * bootmagic, NKRO mode will always be enabled until it is toggled again during a
 * power-up.
 *
 */
//#define FORCE_NKRO

/*
 * Feature disable options
 *  These options are also useful to firmware size reduction.
 */

/* disable debug print */
//#define NO_DEBUG

/* disable print */
//#define NO_PRINT

/* disable action features */
//#define NO_ACTION_LAYER
//#define NO_ACTION_TAPPING
//#define NO_ACTION_ONESHOT

/* disable these deprecated features by default */
#define NO_ACTION_MACRO
#define NO_ACTION_FUNCTION

/* Bootmagic Lite key configuration */
//#define BOOTMAGIC_LITE_ROW 0
//#define BOOTMAGIC_LITE_COLUMN 0

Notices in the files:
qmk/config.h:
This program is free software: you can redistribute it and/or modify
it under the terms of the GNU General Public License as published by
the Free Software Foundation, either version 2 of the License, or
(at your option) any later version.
